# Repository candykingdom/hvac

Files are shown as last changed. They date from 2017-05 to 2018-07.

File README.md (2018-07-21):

# Playa engineering!

## Installing the breadboard in arduino

You have to install the board type "atmega328 on a breadboard". Follow the
instructions in [Minimal Circuit (Eliminating the External
Clock)](https://www.arduino.cc/en/Tutorial/ArduinoToBreadboard)

## Digikey components

Power:

[Sabre flat blade literature](http://www.literature.molex.com/SQLImages/kelmscott/Molex/PDF_Images/987650-5662.PDF)

For a 10 foot run @ 12v 4A, allowing for 3% voltage drop.

Wire Size           14 AWG
Voltage at Max Drop 11.64 V

 *  [Board Side](https://www.digikey.com/product-detail/en/molex-llc/0431601102/WM18483-ND/300116)
 *  [Cable Side](https://www.digikey.com/products/en?keywords=44441-2002)
 *  [Crimp](https://www.digikey.com/product-detail/en/molex-llc/0433750001/WM9174CT-ND/300126)

Motors:
 *  [Board Side](http://www.mouser.com/ProductDetail/Molex/43160-3106/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)
 *  [Cable Side](https://www.digikey.com/product-detail/en/molex-llc/0444412006/WM18467-ND/300100) # Find the cable side version
 *  Same crimps

Data:

 *  [Board Side](https://www.digikey.com/short/3nbvwp)
 *  [Cable Side](https://www.digikey.com/product-detail/en/molex-llc/0511030900/WM13237-ND/3262504)
 *  [Crimp](https://www.digikey.com/product-detail/en/molex-llc/0503518000/WM3320CT-ND/2405712)

More components:

 *  [Through hole potentiometer](https://www.digikey.com/product-detail/en/bourns-inc/PDB12-H4301-103BF/PDB12-H4301-103BF-ND/3780664)
 *  [Through hole toggle switch](https://www.digikey.com/product-detail/en/e-switch/100SP1T1B4M2QE/EG2355-ND/378824)
 *  [Pushbutton Switch (PVA-H2)](https://www.digikey.com/product-detail/en/c-k/Y17P12211FP/401-1135-ND/417718)
 *  [MOSFET](https://www.digikey.com/product-detail/en/nexperia-usa-inc/BUK9Y09-40B,115/1727-4611-1-ND/2531001)
 *  [Fuseholder](https://www.digikey.com/product-detail/en/keystone-electronics/3550-2/36-3550-2-ND/2137310)

TODO:
 *  Mounting holes for the face plate.
 *  Add labels for the switches and pots
 *  The timer button has pin 2 wired to the micro but in real life pin 3 should be it. i.e. the spec says the switches are horizontal but they are actually vertical.
 *  Switch to ARM
 *  The pins that were chosen for i2c turned out to be the same pins that were used for the crystal. The crystal pins required tedious manual intervention to interact with them.

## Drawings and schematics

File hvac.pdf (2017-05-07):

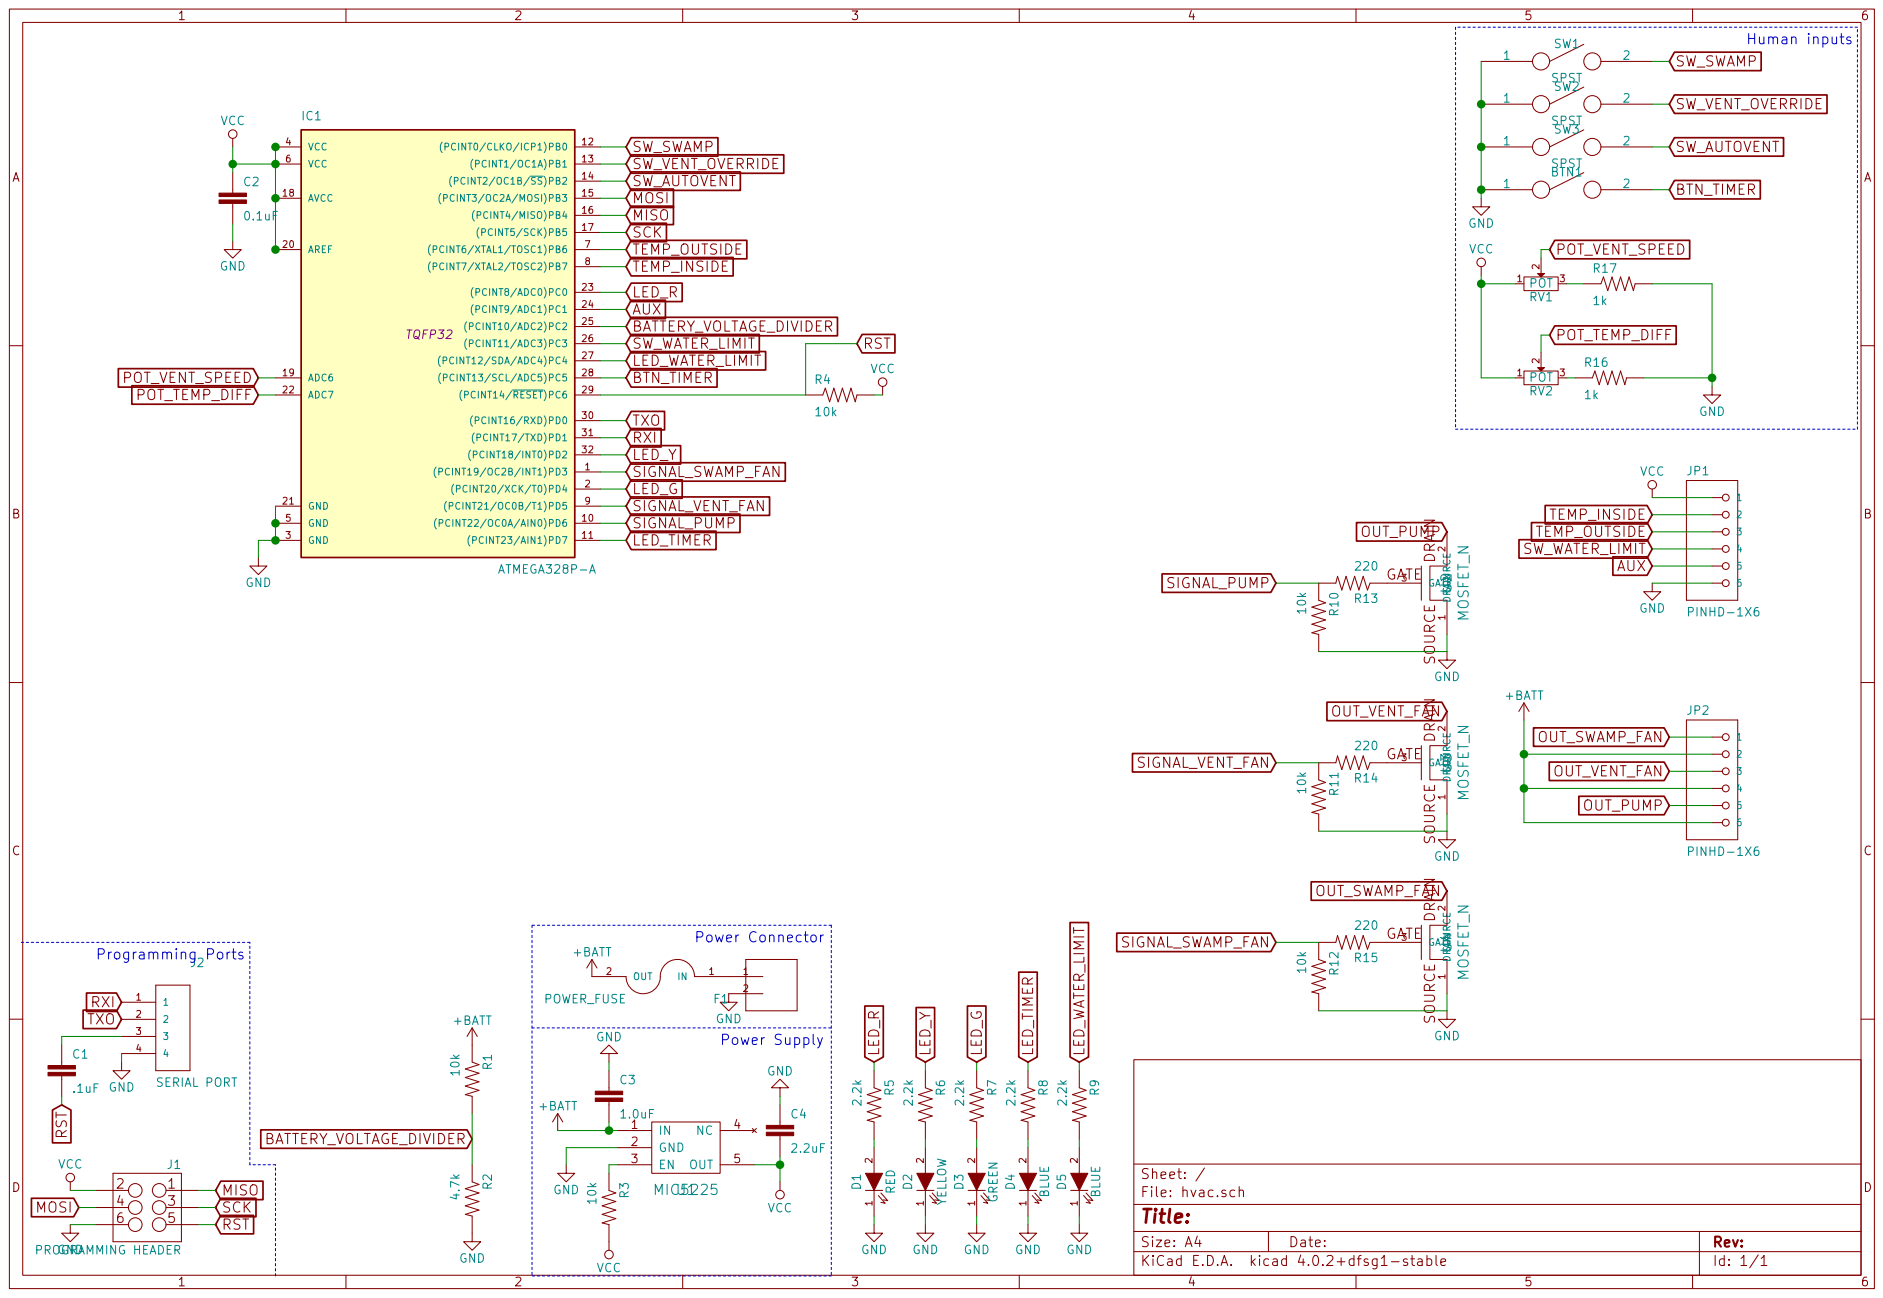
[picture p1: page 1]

1 2 D2 YELLOW 1 2 D3 GREEN LED_R LED_Y LED_G Power Supply GND R8 2.2k
1.0uF R3 10k VCC

Id: 1/1 Title: File: hvac.sch Sheet: /

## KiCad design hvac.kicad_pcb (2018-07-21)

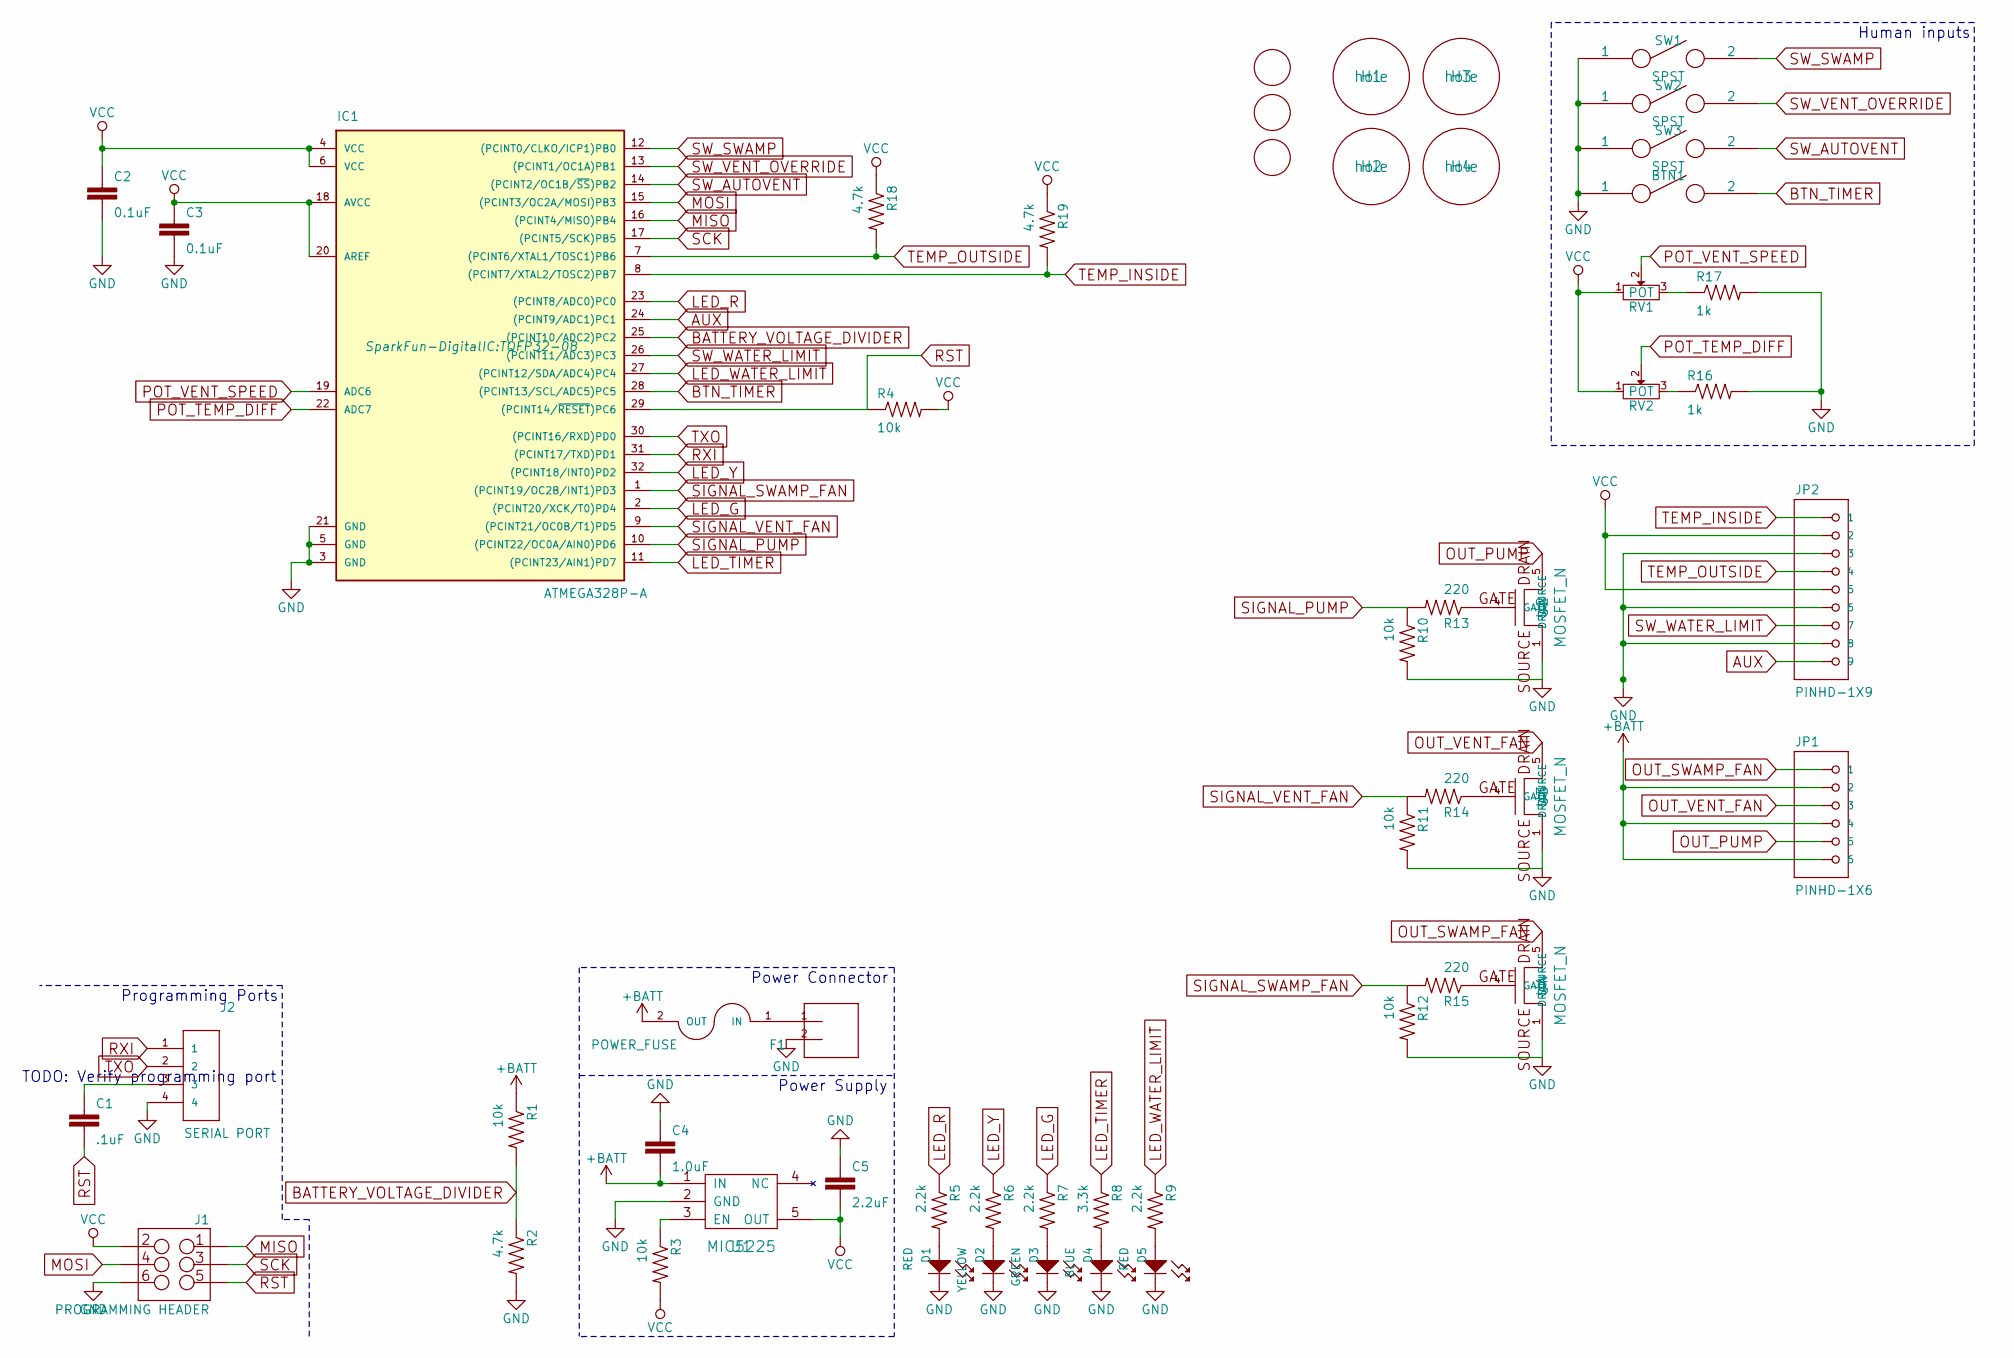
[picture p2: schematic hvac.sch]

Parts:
BTN1: SPST; PVA1-OA-H2
C1: .1uF; C_0603
C2, C3: 0.1uF; C_0603
C4: 1.0uF; C_0603
C5: 2.2uF; C_0603
D1, D5: RED; MF_LEDs-LED0603
D2: YELLOW; MF_LEDs-LED0603
D3: GREEN; MF_LEDs-LED0603
D4: BLUE; MF_LEDs-LED0603
F1: POWER_FUSE; FUSE-3550-2
H1, H2, H3, H4: hole; hole-m2.5
IC1: ATMEGA328P-A; TQFP32-08
J1: PROGRAMMING HEADER; 2X3
J2: SERIAL PORT; 1X04
J3: POWER_INPUT; 1x2-RIGHT_ANGLE-43160-1102
JP1: PINHD-1X6; 1x6-RIGHT_ANGLE-43160-3106
JP2: PINHD-1X9; 1x9-RIGHT_ANGLE-0534260910
M1, M2, M3: FIDUCIAL; FIDUCIAL_1MM
R1, R3, R4, R10, R11, R12: 10k; R_0402
R2, R18, R19: 4.7k; R_0402
R5, R6, R7, R9: 2.2k; R_0402
R8: 3.3k; R_0402
R13, R14, R15: 220; R_0402
R16, R17: 1k; R_0402
RV1, RV2: POT; PDB12-H4301-103BF
SW1, SW2, SW3: SPST; EG2355-ND
U1: MIC5225; SOT-23-5
U2, U3, U4: MOSFET_N; SOT-669_LFPAK_ThermalVias-1

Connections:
+BATT: C4.2, F1.2 (OUT), JP1.2, JP1.4, JP1.6, R1.1, U1.1 (IN)
AUX: IC1.24 ((PCINT9/ADC1)PC1), JP2.9
BATTERY_VOLTAGE_DIVIDER: IC1.25 ((PCINT10/ADC2)PC2), R1.2, R2.1
BTN_TIMER: BTN1.2, IC1.28 ((PCINT13/SCL/ADC5)PC5)
GND: BTN1.1, C2.2, C3.2, C4.1, C5.1, D1.CATH (CATHODE), D2.CATH (CATHODE), D3.CATH (CATHODE), D4.CATH (CATHODE), D5.CATH (CATHODE), IC1.3 (GND), IC1.5 (GND), IC1.21 (GND), J1.6, J2.4, J3.2, JP2.3, JP2.6, JP2.8, R2.2, R10.2, R11.2, R12.2, R16.2, R17.2, SW1.1, SW2.1, SW3.1, U1.2 (GND), U2.1 (SOURCE), U2.2 (SOURCE), U2.3 (SOURCE), U3.1 (SOURCE), U3.2 (SOURCE), U3.3 (SOURCE), U4.1 (SOURCE), U4.2 (SOURCE), U4.3 (SOURCE)
LED_G: IC1.2 ((PCINT20/XCK/T0)PD4), R7.1
LED_R: IC1.23 ((PCINT8/ADC0)PC0), R5.1
LED_TIMER: IC1.11 ((PCINT23/AIN1)PD7), R8.1
LED_WATER_LIMIT: IC1.27 ((PCINT12/SDA/ADC4)PC4), R9.1
LED_Y: IC1.32 ((PCINT18/INT0)PD2), R6.1
MISO: IC1.16 ((PCINT4/MISO)PB4), J1.1
MOSI: IC1.15 ((PCINT3/OC2A/MOSI)PB3), J1.4
unnamed: C1.1, J2.3
unnamed: D1.ANOD (ANODE), R5.2
unnamed: D2.ANOD (ANODE), R6.2
unnamed: D3.ANOD (ANODE), R7.2
unnamed: D4.ANOD (ANODE), R8.2
unnamed: D5.ANOD (ANODE), R9.2
unnamed: F1.1 (IN), J3.1
unnamed: R3.1, U1.3 (EN)
unnamed: R13.1, U2.4 (GATE)
unnamed: R14.1, U3.4 (GATE)
unnamed: R15.1, U4.4 (GATE)
unnamed: R16.1, RV2.3
unnamed: R17.1, RV1.3
OUT_PUMP: JP1.5, U2.5 (DRAIN)
OUT_SWAMP_FAN: JP1.1, U4.5 (DRAIN)
OUT_VENT_FAN: JP1.3, U3.5 (DRAIN)
POT_TEMP_DIFF: IC1.22 (ADC7), RV2.2
POT_VENT_SPEED: IC1.19 (ADC6), RV1.2
RST: C1.2, IC1.29 ((PCINT14/~RESET~)PC6), J1.5, R4.1
RXI: IC1.31 ((PCINT17/TXD)PD1), J2.1
SCK: IC1.17 ((PCINT5/SCK)PB5), J1.3
SIGNAL_PUMP: IC1.10 ((PCINT22/OC0A/AIN0)PD6), R10.1, R13.2
SIGNAL_SWAMP_FAN: IC1.1 ((PCINT19/OC2B/INT1)PD3), R12.1, R15.2
SIGNAL_VENT_FAN: IC1.9 ((PCINT21/OC0B/T1)PD5), R11.1, R14.2
SW_AUTOVENT: IC1.14 ((PCINT2/OC1B/~SS~)PB2), SW3.2
SW_SWAMP: IC1.12 ((PCINT0/CLKO/ICP1)PB0), SW1.2
SW_VENT_OVERRIDE: IC1.13 ((PCINT1/OC1A)PB1), SW2.2
SW_WATER_LIMIT: IC1.26 ((PCINT11/ADC3)PC3), JP2.7
TEMP_INSIDE: IC1.8 ((PCINT7/XTAL2/TOSC2)PB7), JP2.1, R19.2
TEMP_OUTSIDE: IC1.7 ((PCINT6/XTAL1/TOSC1)PB6), JP2.4, R18.2
TXO: IC1.30 ((PCINT16/RXD)PD0), J2.2
VCC: C2.1, C3.1, C5.2, IC1.4 (VCC), IC1.6 (VCC), IC1.18 (AVCC), IC1.20 (AREF), J1.2, JP2.2, JP2.5, R3.2, R4.2, R18.1, R19.1, RV1.1, RV2.1, U1.5 (OUT)

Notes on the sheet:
Power Supply
Human inputs
Power Connector
Programming Ports
TODO: Verify programming port

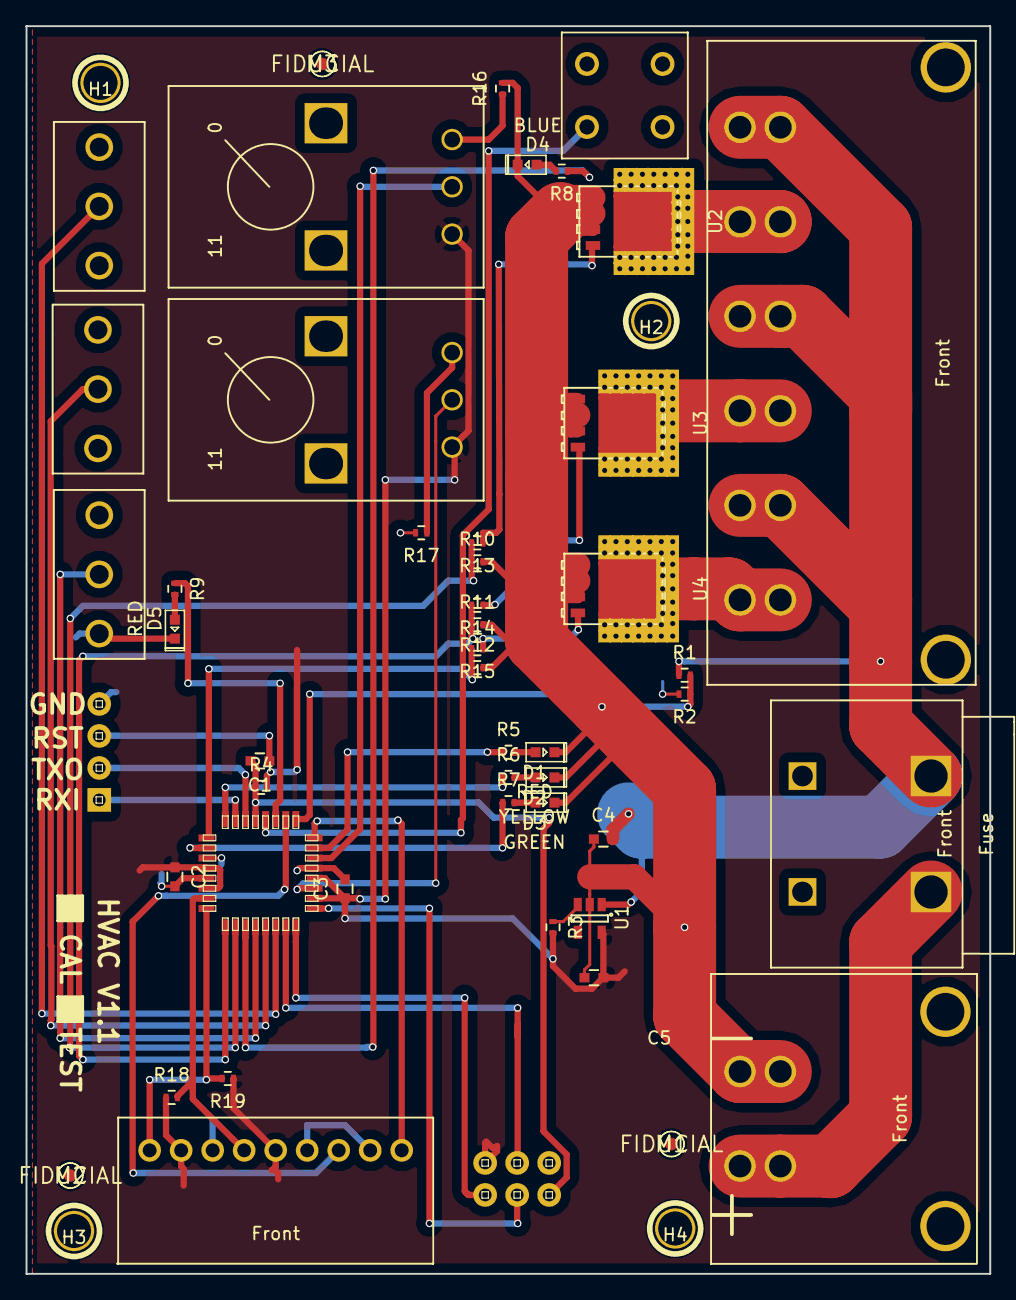
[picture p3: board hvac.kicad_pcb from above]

Board: 2 copper layers, 76.5 x 99.0 mm, 53 parts (0 on the bottom side), 44 nets.

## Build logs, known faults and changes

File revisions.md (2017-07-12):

POTs are probably too close together to be able to mount knobs on them. We decided this is fine for now.

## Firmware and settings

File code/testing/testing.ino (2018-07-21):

  #import "OneWire.h"

// http://www.hobbytronics.co.uk/arduino-atmega328-pinout
const int LED_R = A0; // PC0
const int LED_Y = 2; // PD2
const int LED_G = 4; // PD4
const int LED_WATER_LIMIT = A4; // PC4
const int LED_TIMER = 7; // PD7

const int SW_SWAMP = 8; // PB0
const int SW_VENT_OVERRIDE = 9; // PB1
const int SW_AUTOVENT = 10; // PB2

// http://www.instructables.com/id/22-Bit-Binary-Counter-for-Atmega328/
const int OUT_TEMP_PIN = 2; //PB6/PCINT6;
const int IN_TEMP_PIN = PCINT7;

// NOT VERIFIED  //PD3, // MOSFET Swamp fan
// NOT VERIFIED  //PD5, // MOSFET Vent fan
// NOT VERIFIED  //PD6  // MOSFET Pump

const int outputs[] = {
  LED_R,
  LED_Y,
  LED_G,

  LED_WATER_LIMIT,
  LED_TIMER
};


const int inputs[] = {
  OUT_TEMP_PIN,
  IN_TEMP_PIN
};

const int pullup_inputs[] = {
  SW_SWAMP,
  SW_VENT_OVERRIDE,
  SW_AUTOVENT
};

const float SOURCE_VOLTAGE = 5.0; // TODO: measure that
const float HIGH_DEAD_BAND_PERCENTAGE = 0.0;
const float LOW_DEAD_BAND_PERCENTAGE = 0.0;
// (V_s * R_2) / (R_1 + R_2) = V_out
const float POT_VOLTAGE_HIGH = (SOURCE_VOLTAGE * 10000) / (1000 + 10000) - (HIGH_DEAD_BAND_PERCENTAGE * SOURCE_VOLTAGE);
const float POT_VOLTAGE_LOW  = (SOURCE_VOLTAGE * 10)    / (1000 + 10)    + ( LOW_DEAD_BAND_PERCENTAGE * SOURCE_VOLTAGE);
const long POT_VALUE_HIGH = (POT_VOLTAGE_HIGH / SOURCE_VOLTAGE) * 1023;
const long POT_VALUE_LOW  = (POT_VOLTAGE_LOW / SOURCE_VOLTAGE) * 1023;

OneWire * inTempSensor;
OneWire * outTempSensor;


void setup() {
  Serial.begin(9600);
  
  // put your setup code here, to run once:
  for(int i = 0; i < sizeof(outputs); i++) {
    int output = outputs[i];
    pinMode(output, OUTPUT);
    digitalWrite(output, LOW);
  }

  for(int i = 0; i < sizeof(inputs); i++) {
    int input = inputs[i];
    pinMode(input, INPUT);
  }
  
  for(int i = 0; i < sizeof(pullup_inputs); i++) {
    int input = pullup_inputs[i];
    pinMode(input, INPUT_PULLUP);
  }

  // Set up onewire pins
  //OneWire( uint8_t pinArg, uint8_t portArg, uint8_t bitmaskArg, uint8_t *outputRegArg, uint8_t *inputRegArg, uint8_t *modeRegArg);
  uint8_t pinArg        = IN_TEMP_PIN;
  uint8_t bitmaskArg    = 1 << 6;    // PB7... so 7 // digitalPinToBitMask(pin);
  uint8_t *outputRegArg = &PORTB;    // portOutputRegister(port);
  uint8_t *inputRegArg  = &PINB;     // portInputRegister(port);
  uint8_t *modeRegArg   = &DDRB;     // portModeRegister(port);
  inTempSensor = new OneWire(pinArg, bitmaskArg, outputRegArg, inputRegArg, modeRegArg);

  pinArg        = OUT_TEMP_PIN;
  bitmaskArg    = 1 << 4;    // PB6... so 6 // digitalPinToBitMask(pin);
  outputRegArg  = &PORTC;    // portOutputRegister(port);
  inputRegArg   = &PINC;     // portInputRegister(port);
  modeRegArg    = &DDRC;     // portModeRegister(port);
  outTempSensor = new OneWire(pinArg, bitmaskArg, outputRegArg, inputRegArg, modeRegArg);
  // Turn on to prove a point... what point I'm not sure.
  DDRC = 0b11111111;
  PORTC = 0b11111111;
  outTempSensor->digiWrite(1);
    
  digitalWrite(LED_R, HIGH);
  digitalWrite(LED_Y, LOW);
  digitalWrite(LED_G, LOW);
  pause();
  digitalWrite(LED_Y, HIGH);
  pause();
  digitalWrite(LED_G, HIGH);
  pause();
  digitalWrite(LED_R, LOW);
  digitalWrite(LED_Y, LOW);
  digitalWrite(LED_G, LOW);
  pause();

  digitalWrite(LED_TIMER, HIGH);

  // Datasheet 18.2.3. 
  //DDRB = 0b00000000;
  //PORTB = 0b11111111;
}

void pause() {
  delay(20);
}

void red() {
  digitalWrite(LED_G, LOW);
  //digitalWrite(LED_Y, LOW);
  digitalWrite(LED_R, HIGH);
}
void yellow() {
  digitalWrite(LED_R, LOW);
  digitalWrite(LED_G, LOW);
  digitalWrite(LED_Y, HIGH);
}
void green() {
  digitalWrite(LED_R, LOW);
  //digitalWrite(LED_Y, LOW);
  digitalWrite(LED_G, HIGH);
}

bool b = false;
bool y = false;
void loop() {
  Serial.println("Testing");
  //DDRC = 0b11111111;
  //PORTC = 0b11111111;
  //outTempSensor->digiWrite(1);

  //outTempSensor->digiWrite(inTempSensor->digiRead());
/*
  int temp = 0;
  //temp = inTempSensor->getTemp();
  for (float i = 0; i < temp; i++) {
    //digitalWrite(LED_Y, y = !y);
    outTempSensor->digiWrite(1);
    digitalWrite(LED_Y, y = !y);
    delay(100);
  }
  outTempSensor->digiWrite(1);
  delay(100);
  outTempSensor->digiWrite(0);
  digitalWrite(LED_TIMER, b = !b);
  delay(500);
/**/}  

/*  
  int button;
  //button = digitalRead(SW_SWAMP);
  button = digitalRead(SW_AUTOVENT);
  //button = digitalRead(SW_VENT_OVERRIDE);
  if (button == HIGH) {
    green();
  } else {
    red();
  }
*/
  /*if (temp < 64) {
    //if (temp > -1) {
      //Serial.print("A");
    //}
  //}
  /** /
  for(int i = 0; i < sizeof(pins); i++) {
    int PIN = pins[i];
    // put your main code here, to run repeatedly:
    digitalWrite(PIN, HIGH);
  }
  pause();
  for(int i = 0; i < sizeof(pins); i++) {
    int PIN = pins[i];
    // Turn off all the pins (disabled for testing)
    //digitalWrite(PIN, LOW);
  }
  pause();
  /**/

  /** Read from the pot * /
  long value = analogRead(POT_VENT);
  if (value < POT_VALUE_LOW) {
    red();
  }  else if (value < ((POT_VALUE_LOW + POT_VALUE_HIGH) / 2)) {
    yellow();
  } else {
    green();
  }
  }
  /**/

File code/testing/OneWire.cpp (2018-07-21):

/*
Copyright (c) 2007, Jim Studt

Updated to work with arduino-0008 and to include skip() as of
2007/07/06. --RJL20

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
Much of the code was inspired by Derek Yerger's code, though I don't
think much of that remains.  In any event that was..
    (copyleft) 2006 by Derek Yerger - Free to distribute freely.

The CRC code was excerpted and inspired by the Dallas Semiconductor 
sample code bearing this copyright.
//---------------------------------------------------------------------------
// Copyright (C) 2000 Dallas Semiconductor Corporation, All Rights Reserved.
//
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
// Except as contained in this notice, the name of Dallas Semiconductor
// shall not be used except as stated in the Dallas Semiconductor
// Branding Policy.
//--------------------------------------------------------------------------
*/

#include "OneWire.h"

extern "C" {

#if (ARDUINO >= 100)
#include <Arduino.h>
#else
#include <WProgram.h>
#endif

#include <avr/io.h>
#include "pins_arduino.h"
}


OneWire::OneWire( uint8_t pinArg, uint8_t bitmaskArg, uint8_t *outputRegArg, uint8_t *inputRegArg, uint8_t *modeRegArg)
{
    pin = pinArg;
    // Port doesn't matter if you're not calling into the arduino helper methods in here.
    //port = portArg; // digitalPinToPort(pin);
    bitmask =  bitmaskArg; // digitalPinToBitMask(pin);
    outputReg = outputRegArg; // portOutputRegister(port);
    inputReg = inputRegArg; //portInputRegister(port);
    modeReg = modeRegArg; // portModeRegister(port);
#if ONEWIRE_SEARCH
    reset_search();
#endif
}



//
// Perform the onewire reset function.  We will wait up to 250uS for
// the bus to come high, if it doesn't then it is broken or shorted
// and we return a 0;
//
// Returns 1 if a device asserted a presence pulse, 0 otherwise.
//
uint8_t OneWire::reset() {
    uint8_t r;
    uint8_t retries = 125;

    // wait until the wire is high... just in case
    pinModeOneWire(INPUT);
    do {
	if ( retries-- == 0) return 0;
	delayMicroseconds(2); 
    } while( !digiRead());
    
    digiWrite(0);   // pull low for 500uS
    pinModeOneWire(OUTPUT);
    delayMicroseconds(500);
    pinModeOneWire(INPUT);
    delayMicroseconds(65);
    r = !digiRead();
    delayMicroseconds(490);
    return r;
}

//
// Write a bit. Port and bit is used to cut lookup time and provide
// more certain timing.
//
void OneWire::write_bit(uint8_t v) {
    static uint8_t lowTime[] = { 55, 5 };
    static uint8_t highTime[] = { 5, 55};
    
    v = (v&1);
    *modeReg |= bitmask;  // make pin an output, do first since we
                          // expect to be at 1
    *outputReg &= ~bitmask; // zero
    delayMicroseconds(lowTime[v]);
    *outputReg |= bitmask; // one, push pin up - important for
                           // parasites, they might start in here
    delayMicroseconds(highTime[v]);
}

void OneWire::digiWrite(uint8_t v) {
  if (v) {
    *outputReg |= bitmask; // one, push pin up - important for
                           // parasites, they might start in here
  } else {
    *outputReg &= ~bitmask; // zero
  }
}

uint8_t OneWire::digiRead() {
  return (*inputReg & bitmask) ? 1: 0;
}

void OneWire::pinModeOneWire(uint8_t val) {
  if (val == OUTPUT) {
    *modeReg |= bitmask;
  } else if (val == INPUT) {
    *modeReg &= ~bitmask;  // make pin an input by anding with the compleent of the bitmask

  }
}

//
// Read a bit. Port and bit is used to cut lookup time and provide
// more certain timing.
//
uint8_t OneWire::read_bit() {
    uint8_t r;
    
    *modeReg |= bitmask;    // make pin an output, do first since we expect to be at 1
    *outputReg &= ~bitmask; // zero
    delayMicroseconds(1);
    *modeReg &= ~bitmask;     // let pin float, pull up will raise
    delayMicroseconds(5);          // A "read slot" is when 1mcs > t > 2mcs
    r = ( *inputReg & bitmask) ? 1 : 0; // check the bit
    delayMicroseconds(50);        // whole bit slot is 60-120uS, need to give some time
    
    return r;
}

//
// Write a byte. The writing code uses the active drivers to raise the
// pin high, if you need power after the write (e.g. DS18S20 in
// parasite power mode) then set 'power' to 1, otherwise the pin will
// go tri-state at the end of the write to avoid heating in a short or
// other mishap.
//
void OneWire::write(uint8_t v, uint8_t power) {
    uint8_t bitMask;
    
    for (bitMask = 0x01; bitMask; bitMask <<= 1) {
	OneWire::write_bit( (bitMask & v)?1:0);
    }
    if ( !power) {
	    pinModeOneWire(INPUT);
	    digiWrite(0);
    }
}

//
// Read a byte
//
uint8_t OneWire::read() {
    uint8_t bitMask;
    uint8_t r = 0;
    
    for (bitMask = 0x01; bitMask; bitMask <<= 1) {
	if ( OneWire::read_bit()) r |= bitMask;
    }
    return r;
}

//
// Do a ROM select
//
void OneWire::select( uint8_t rom[8])
{
    int i;

    write(0x55,0);         // Choose ROM

    for( i = 0; i < 8; i++) write(rom[i],0);
}

//
// Do a ROM skip
//
void OneWire::skip()
{
    write(0xCC,0);         // Skip ROM
}

void OneWire::depower()
{
    pinModeOneWire(INPUT);
}

#if ONEWIRE_SEARCH

//
// You need to use this function to start a search again from the beginning.
// You do not need to do it for the first search, though you could.
//
void OneWire::reset_search()
{
    uint8_t i;
    
    searchJunction = -1;
    searchExhausted = 0;
    for( i = 7; ; i--) {
	address[i] = 0;
	if ( i == 0) break;
    }
}
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

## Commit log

2017-05-06 Add kicad files
    [hvac.kicad_pcb, hvac.sch]
2017-05-07 Add MIC5225 to homebrew and place power supply on board
    [hvac.sch]
2017-05-07 Add components
    * Add power supply
    * Add LEDs
    * Add Serial
    * Add programming header
    [hvac.sch]
2017-05-07 Wire up inputs and outputs
    [hvac.sch]
2017-05-07 Hook up all components and fix warnings
    TODO: Set up output stages
    [hvac.sch]
2017-05-07 Add mosfets for driving fans and pump
    [hvac.sch]
2017-05-07 Switch to 220ohm resistors
    [hvac.sch]
2017-05-07 Add notes on connectors
2017-05-07 Switch to 6 pin header
    [hvac.sch]
2017-05-07 Switch to 9 pin header and provide ground/vcc for every temp sensor
    [hvac.sch]
2017-05-07 Add a part for EG2355-ND (throw switch)
2017-05-08 Add some footprints
    [_saved_hvac.sch]
2017-05-08 Begin routing
    [_saved_hvac.sch, hvac.sch]
2017-06-07 Lay out all the parts in semi logical places
    [hvac.kicad_pcb]
2017-06-07 Create hole footprint and route a few small things
    [hvac.sch]
2017-06-07 Add holes to the pcb layout
    [_saved_hvac.sch, hvac.kicad_pcb]
2017-06-07 Add fiducials to the board for the pick n place
    [_saved_hvac.sch, hvac.kicad_pcb, hvac.sch]
2017-06-07 Partial routing
    [hvac.kicad_pcb]
2017-06-07 More routing
    [hvac.kicad_pcb]
2017-06-11 First pass routing everything
    [hvac.kicad_pcb]
2017-06-11 Fix remaining DRC errors
    [hvac.kicad_pcb]
2017-06-11 Generate gerber files per macrofab instructions
    https://macrofab.com/help/creating-managing-ordering-pcbs/creating-pcb-projects-kicad/
    [hvac-B.Cu.gbl, hvac-B.Mask.gbs, hvac-B.Paste.gbp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]
2017-06-11 Add version info to the board
    [hvac.kicad_pcb]
2017-06-11 Regenerate gerber files
    [hvac-B.Cu.gbl, hvac-B.Mask.gbs, hvac-B.Paste.gbp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]
2017-07-12 Move pieces to fit better
    [hvac.kicad_pcb, hvac.sch]
2017-07-12 Add pullup resistors for temperature probes
    [hvac.kicad_pcb, hvac.sch]
2017-07-12 Bump revision + minor changes
    [hvac-B.Cu.gbl, hvac-B.Mask.gbs, hvac-B.Paste.gbp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]
2018-07-21 Saving last years changes... dunno
    [hvac.kicad_pcb]

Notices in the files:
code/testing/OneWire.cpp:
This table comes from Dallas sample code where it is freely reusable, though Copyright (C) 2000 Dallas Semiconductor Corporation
